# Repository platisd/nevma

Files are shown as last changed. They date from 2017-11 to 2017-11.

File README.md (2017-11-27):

# Nevma
A USB gadget to transform your gestures to keyboard and mouse events.

nevma

## Overview
Nevma (means "gesture" in Greek) is a simple to build, program and use device that translates your hand gestures into keyboard and mouse input. Just plug it in your USB port and magically wave through your presentations, documents, pictures, songs and the like.

## How does it work
Nevma implements two basic functions. Gesture recognition and keyboard and mouse event generation over USB. The former is realized through the [APDS-9960](https://learn.sparkfun.com/tutorials/apds-9960-rgb-and-gesture-sensor-hookup-guide) sensor while the latter by utilizing the USB HID capabilities of the ATMega32U4 chip.

Nevma can by default recognize a plethora of gestures; swipe left, right, up, down, and moving the hand closer or further from the sensor, using the [APDS-9960 library](https://github.com/sparkfun/SparkFun_APDS-9960_Sensor_Arduino_Library) by Sparkfun.

## Components
* [Nevma board PCB](https://www.pcbway.com/project/shareproject/Nevma__Gesture_control_for_the_masses.html)
* [3D printed case](https://www.tinkercad.com/things/h5ymCb1lX3J)
* [Mini SS Micro ATMEGA32U4](https://www.aliexpress.com/item/New-Arrival-Mini-SS-Micro-ATMEGA32U4-Pro-Micro-Module-Board-Compatible-For-Arduino/32777411276.html)
* [APDS-9960 module](https://www.aliexpress.com/item/GY-9960LLC-APDS-9960-RGB-and-Gesture-Sensor-Module-I2C-Breakout-for-Arduino/32746930049.html)

## Media
*  [Nevma: Gesture control for the masses](https://platis.solutions/blog/2017/11/27/nevma-gesture-control-for-the-masses/)

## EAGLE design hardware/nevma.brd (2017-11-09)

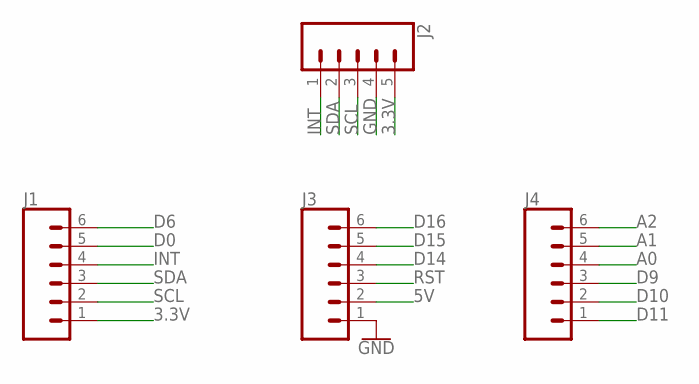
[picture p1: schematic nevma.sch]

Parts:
J1, J3, J4: CONN_06LOCK; 1X06_LOCK
J2: CONN_05LOCK; 1X05_LOCK

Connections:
3.3V: J1.1, J2.5
5V: J3.2
A0: J4.4
A1: J4.5
A2: J4.6
D0: J1.5
D6: J1.6
D9: J4.3
D10: J4.2
D11: J4.1
D14: J3.4
D15: J3.5
D16: J3.6
GND: J2.4, J3.1
INT: J1.4, J2.1
RST: J3.3
SCL: J1.2, J2.3
SDA: J1.3, J2.2

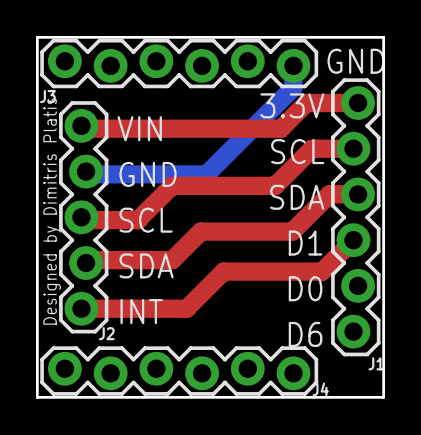
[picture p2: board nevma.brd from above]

Board: 2 copper layers, 19.2 x 20.0 mm, 4 parts (0 on the bottom side), 5 nets.

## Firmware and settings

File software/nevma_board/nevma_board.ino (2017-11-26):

#include <Keyboard.h>
#include <Mouse.h>
#include <SparkFun_APDS9960.h>

SparkFun_APDS9960 gestureSensor;
const unsigned short GESTURE_INT_PIN = 1;

volatile boolean hasMovement = false;

/**
   The main business logic. Translates gestures to keyboard events.
*/
void handleGesture() {
  if (gestureSensor.isGestureAvailable()) {
    switch (gestureSensor.readGesture()) {
      case DIR_UP:
        Keyboard.press(KEY_LEFT_ARROW);
        break;
      case DIR_DOWN:
        Keyboard.press(KEY_RIGHT_ARROW);
        break;
      case DIR_LEFT:
        Mouse.move(0, 0, -10);
        break;
      case DIR_RIGHT:
        Mouse.move(0, 0, 10);
        break;
      case DIR_NEAR:
        Keyboard.press(' ');
        break;
      case DIR_FAR:
        Keyboard.press(KEY_ESC);
        break;
      default:
        break;
    }
    Keyboard.releaseAll();
  }
}

/**
   Gets called whenever the gesture module signals there are new data to be sent
*/
void transmissionReady() {
  hasMovement = true;
}

/**
   Initializes gesture sensor
  @return whether gesture sensor initialization was successful
*/
boolean initializeGestureSensor() {
  return gestureSensor.init() && gestureSensor.enableGestureSensor(true);
}

void setup() {
  Keyboard.begin();
  Mouse.begin();
  attachInterrupt(digitalPinToInterrupt(GESTURE_INT_PIN), transmissionReady, FALLING);
  boolean initializationSuccessful = initializeGestureSensor();
  // If ADPS sensor failed to initialize, block and send error messages via Serial
  if (!initializationSuccessful) {
    Serial.begin(9600);
    while (!initializationSuccessful) {
      Serial.println("Error while initializing the gesture sensor");
      delay(10000);
    }
  }
}

void loop() {
  if (hasMovement) {
    handleGesture();
    hasMovement = false;
    // Reinitialize as workaround for sensor hanging when gesturing too fast
    initializeGestureSensor();
  }
}

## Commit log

2017-10-22 Add initial rev. 0 board
    [nevma.brd, nevma.sch]
2017-10-22 Correct resistor value
    [nevma.sch]
2017-10-22 Decrease board size
    [nevma.brd]
2017-10-27 Reduce board size This will allower the better fit of the USB socket
    [nevma.brd]
2017-11-01 New concept based on atmega32u4 board
    HW rev. 2
    [nevma.brd, nevma.sch]
2017-11-08 Fix header position - HW rev. 2
    * Also slightly decrease board size
    [nevma.brd]
2017-11-08 Add nevma board firmware
2017-11-09 Decrease board size further
    [nevma.brd]
2017-11-09 Bugfix: Workaround for sensor hanging when gesturing too fast
    [nevma_board.ino]
2017-11-26 Add reversed controls and mouse scroll
    [nevma_board.ino]
2017-11-26 Add link to purchase PCB
2017-11-26 Add link to 3D printed case

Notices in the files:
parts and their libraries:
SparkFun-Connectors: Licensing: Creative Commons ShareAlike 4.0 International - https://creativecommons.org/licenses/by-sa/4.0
